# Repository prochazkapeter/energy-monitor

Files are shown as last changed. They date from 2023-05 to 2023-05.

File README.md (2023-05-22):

# energy-monitor

Energy consumption monitoring device using NodeMCU-32S and PZEM-004T v 3.0 module over MQTT.
This device could be easily integrated to Home Assistant using Mosquitto broker add-on.
You could visualize the data using standard hassio tools or implement ingestion to InfluxDB and
use Grafana.

This repo also contains 3D model of custom enclosure, which was printed using Prusa Mini+.
The ESP32 dev kit is mounted on custom PCB with DC power supply from 230 V. The PCB schematics 
are located in em_schematic directory.

## Quick Start

- download firmware and power up the device
- device acts as an AP, connect to it via mobile phone
- fill in Wi-Fi credentials and MQTT broker details

### MQTT Topics
- device sends measurements in JSON format to **homeenergy/sensor1** (can be changed in config.h)
- device listens to commands on **esp32/sensor1**
- data format -> {"voltage":"231.1","current":"0.540","power":"92.100",
  "energy":"18.53","projection":"180640","frequency":"50.0","pfactor":"0.74"}
 
### MQTT Commands
- **on**/**off** -> control the blue LED on ESP32 dev kit
- **resetEnergy** -> reset energy counter
- **resetWiFi** -> reset WiFi credentials
- **restartESP** -> restart the device
- **datefrom-dd/mm/yy** -> set start of the billing period
- **billdate-dd/mm/yy** -> set end of the billing period

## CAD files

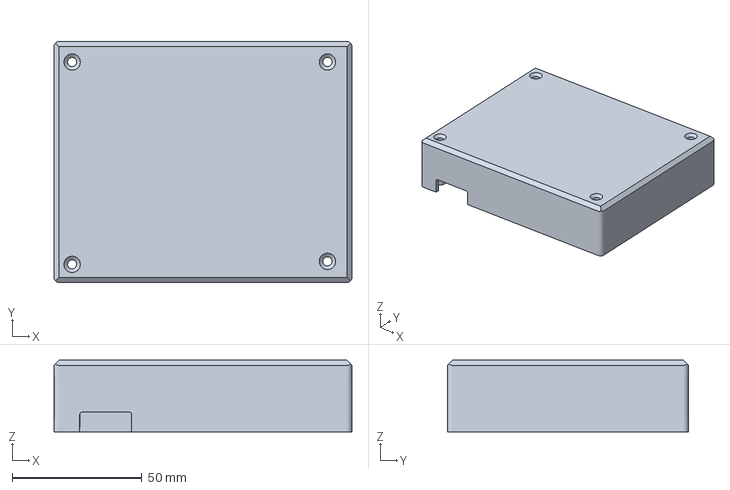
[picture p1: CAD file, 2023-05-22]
3d_model_enclosure/top.3mf
115.0 x 93.0 x 27.6 mm

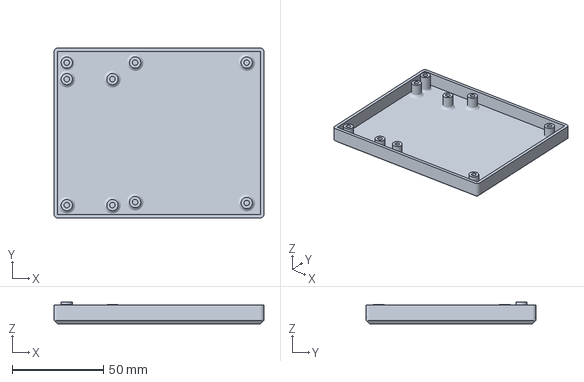
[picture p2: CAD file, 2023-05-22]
3d_model_enclosure/bottom.3mf
115.0 x 93.0 x 12.0 mm

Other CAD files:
3d_model_enclosure/enclosure_design_fusion360.f3z

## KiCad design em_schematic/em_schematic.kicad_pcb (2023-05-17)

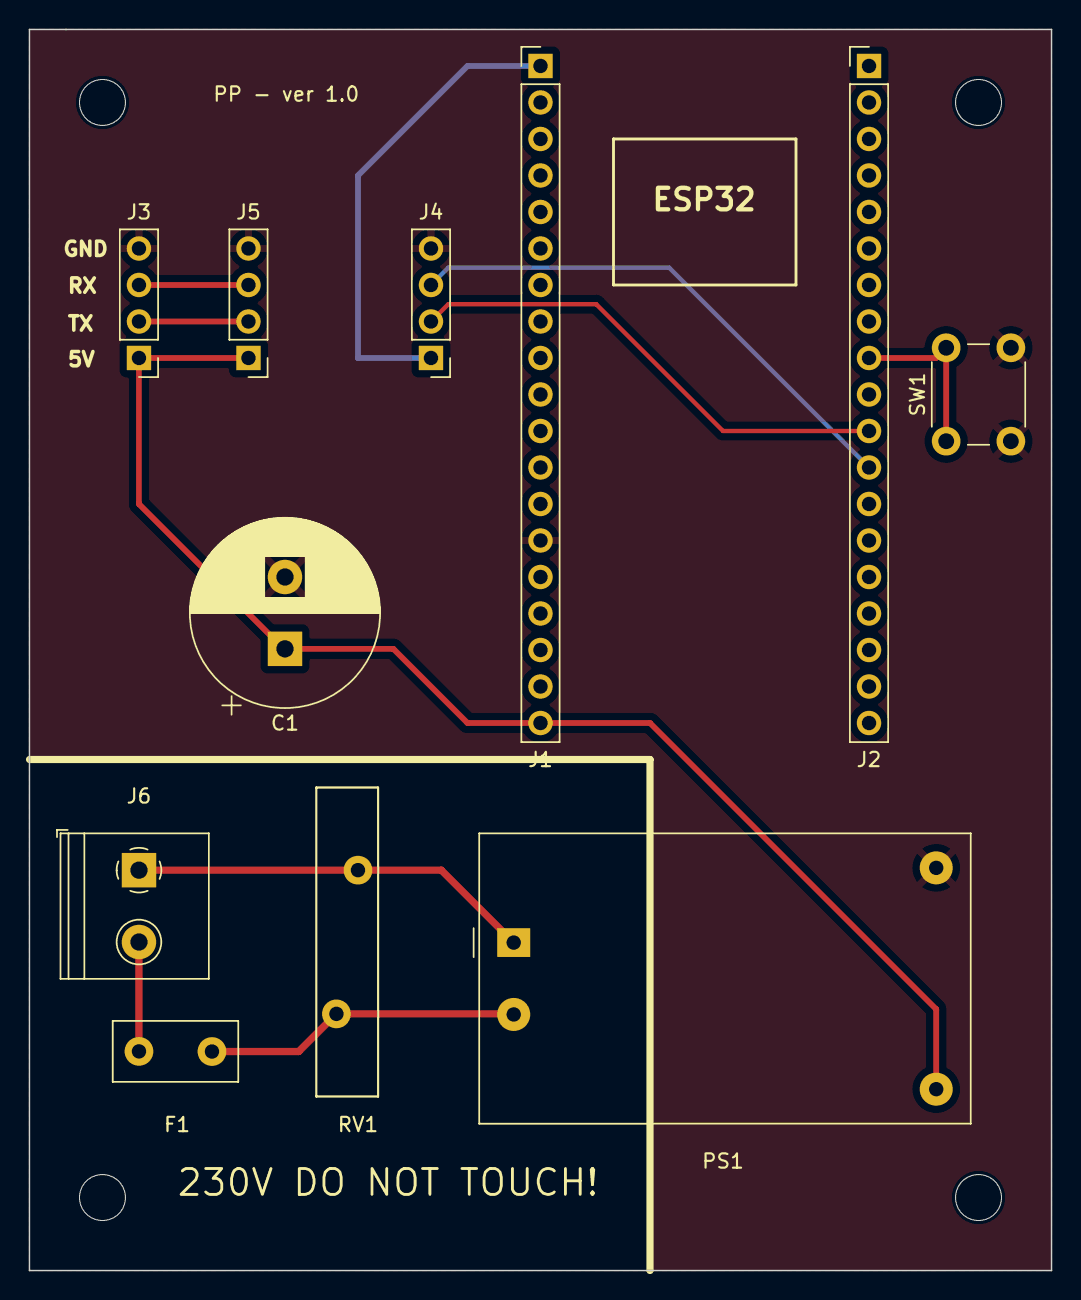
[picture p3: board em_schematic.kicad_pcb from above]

Board: 2 copper layers, 71.1 x 86.4 mm, 11 parts (0 on the bottom side), 11 nets.

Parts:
C1: C_Polarized; CP_Radial_D13.0mm_P5.00mm
F1: Fuse; Fuse_Littelfuse_395Series
J1, J2: Conn_01x19; PinHeader_1x19_P2.54mm_Vertical
J3, J4, J5: Conn_01x04; PinHeader_1x04_P2.54mm_Vertical
J6: Screw_Terminal_01x02; TerminalBlock_Philmore_TB132_1x02_P5.00mm_Horizontal
PS1: HLK-PM01; Converter_ACDC_HiLink_HLK-PMxx
RV1: Varistor; RV_Disc_D21.5mm_W4.3mm_P10mm
SW1: SW_Push; SW_PUSH_6mm_H5mm

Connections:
+5V: C1.1, J1.19, J3.1, J5.1, PS1.4 (+Vout)
GND: C1.2, J1.14, J3.4, J4.4, J5.4, PS1.3 (-Vout), SW1.2
unnamed: J1.1, J4.1
unnamed: J2.9, SW1.1
unnamed: J2.11, J4.2
unnamed: J2.12, J4.3
unnamed: J3.2, J5.2
unnamed: J3.3, J5.3
unnamed: J6.1, PS1.1 (AC/L), RV1.1
unnamed: F1.1, J6.2
unnamed: F1.2, PS1.2 (AC/N), RV1.2

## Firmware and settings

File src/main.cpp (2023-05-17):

#include "measurement.h"
#include "network.h"

// Public variables
PZEM004Tv30 pzem(Serial2, 16, 17);
WiFiClient espClient;
PubSubClient client(espClient);
WiFiManager wm;

long lastMsg = 0;
int cycles = 0;

void setup()
{
    Serial.begin(115200);
    // Configure GPIO for LED and user BUTTON
    pinMode(LED_PIN, OUTPUT);
    pinMode(BUTTON, INPUT_PULLUP);
    // If the user button is pressed immediately after boot,
    // reset Wi-Fi configuration
    if (digitalRead(BUTTON) == LOW) {
        wm.resetSettings();
    }

    // Connect to Wi-Fi and configure MQTT connection
    setup_wifi();

    // Init and get time from NTP
    configTime(3600, 3600, ntp_server);
    // Print billing period from flash memory
    print_date("datefrom");
    print_date("billdate");
}

void loop()
{
    if (WiFi.status() != WL_CONNECTED) {
        ESP.restart();
    }
    if (!client.connected()) {
        reconnect();
    }
    if (digitalRead(BUTTON) == LOW) {
        reset_wifi_button();
    }
    client.loop();

    long now = millis();
    // do measurement every 10 seconds
    if (now - lastMsg > 10000) {
        lastMsg = now;
        cycles++;

        String str_payload = measure_data();

        if (cycles > 6) { // every 1 minute
            cycles = 0;
            project_energy();
        }

        // String str_payload = "Test string from ESP32 to Home Assistant";
        Serial.print("Sending data -> ");
        Serial.println(str_payload);
        client.publish(mqtt_publish_topic, str_payload.c_str());
    }
}

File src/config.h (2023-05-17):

#include "time.h"
#include <ArduinoJson.h>
#include <PZEM004Tv30.h>
#include <Preferences.h>
#include <PubSubClient.h>
#include <WiFiManager.h>
#include <Wire.h>

#define LED_PIN 2
#define BUTTON 18

// Configuration
#define ntp_server "ntp.nic.cz"
#define AP_NAME "Energy Monitor"
#define AP_PASS "emonitor"
#define mqtt_publish_topic "homeenergy/sensor1" // "homeenergy/test"
#define mqtt_subscribe_topic "esp32/sensor1"    // "esp32/test"
#define WIFI_CONNECTION_TIMEOUT 120
#define WIFI_CONFIGPORTAL_TIMEOUT 60

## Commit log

2022-12-26 Created functions for calibration and measurement of RMS Voltage
2023-05-17 KiCad schematic
    [em_schematic-B_Cu.gbr, em_schematic-B_Mask.gbr, em_schematic-B_Silkscreen.gbr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]
2023-05-22 added 3d files for prototype enclosure
    [bottom.3mf, enclosure_design_fusion360.f3z, top.3mf]
